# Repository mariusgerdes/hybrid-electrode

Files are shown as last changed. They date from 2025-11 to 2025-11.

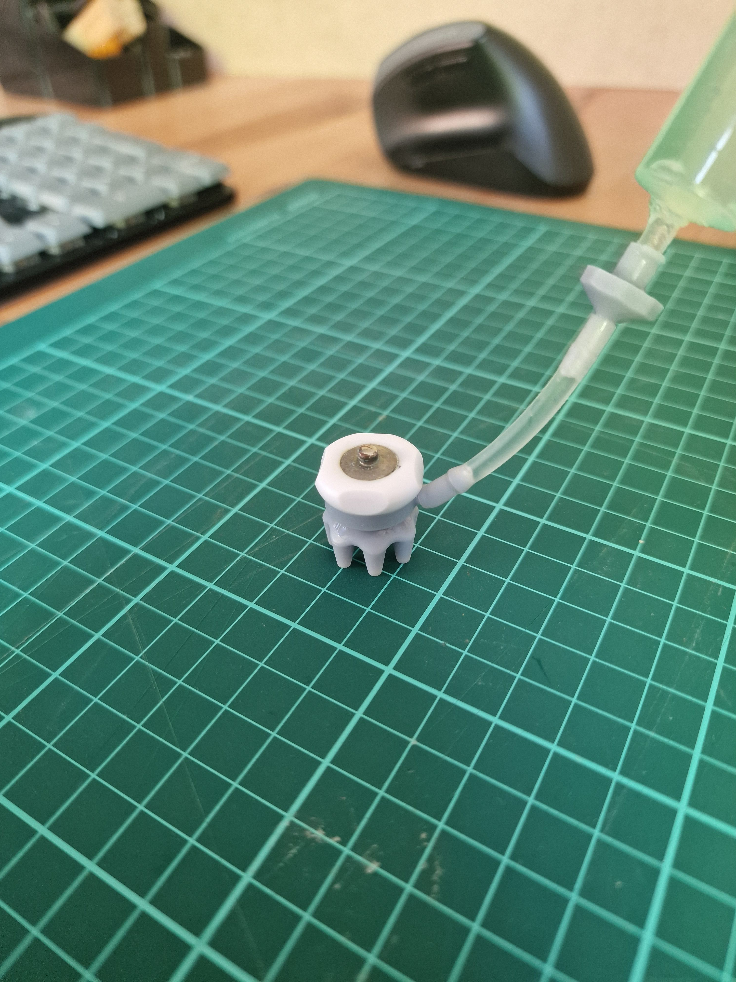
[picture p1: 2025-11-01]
video_and_photo/fillingSyringe.jpg

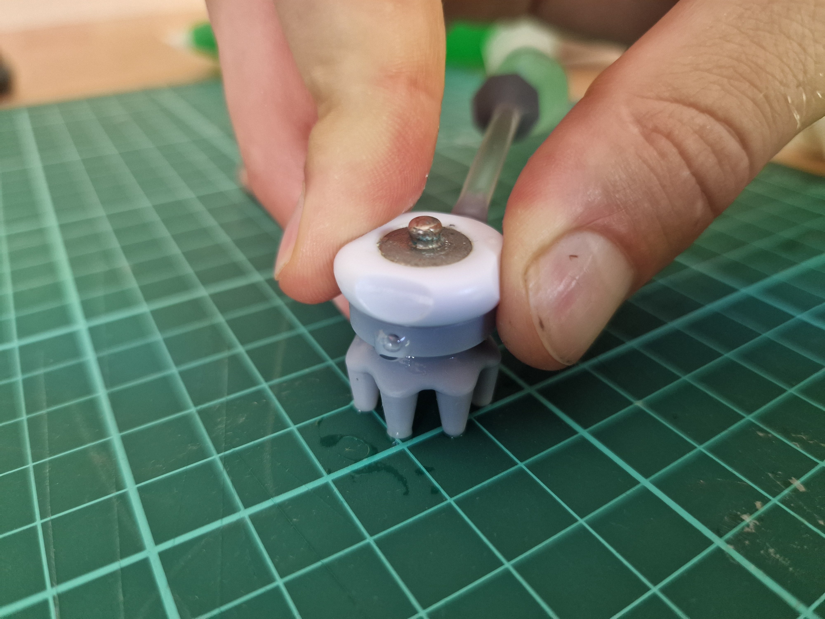
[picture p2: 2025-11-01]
video_and_photo/filledElectrode.jpg

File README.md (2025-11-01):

# RPH-Trode: A Rapid Prototyping Approach to Patient Friendly Hybrid EEG Electrodes



## Authors

**Marius Gerdes¹**, **Simon Stock²**, **Heiko Maier³**, **Lukas Feckl¹**, **Florian Mazura¹**, **Wilhelm Stork¹**

¹ ITIV, Karlsruhe Institute of Technology, Karlsruhe, Germany  
² Faculty of Engineering, TH Rosenheim, Rosenheim, Germany  
³ Computer Aided Medical Procedures, Technical University of Munich, Munich, Germany

## Abstract

The demand for high-quality electroencephalography (EEG) is growing, yet conventional electrodes present a significant bottleneck. Wet electrodes offer excellent signal quality but are hindered by long setup times, gel residue, and signal degradation from drying, making them unsuitable for long-term or mobile use. Conversely, dry electrodes are convenient but often fail to provide the requisite signal-to-noise levels, especially during subject motion. 

This paper introduces a novel hybrid EEG electrode designed to bridge this gap. By employing a closed-loop channel system for precise electrolyte delivery, the electrode combines the signal quality of wet electrodes with the convenience of dry electrodes. We utilized stereolithography (SLA) 3D-printing for easy rapid prototyping of the electrode geometry. 

Experimental validation demonstrates that the hybrid electrode achieves performance comparable to the wet electrode gold standard, maintains stable contact impedance over extended periods, and provides robust signal acquisition during subject motion, including walking. This approach enables high-quality, long-term, and truly mobile EEG recordings, opening new possibilities for both clinical and consumer neurotechnology.

## Keywords

EEG, hybrid electrode, rapid prototyping, SLA, mobile EEG, BCI, SSVEP

## Repository Contents

###  Data & Results
Summary tables of experimental results including:
- Impedance measurements over one-hour recording sessions
- CCA (Canonical Correlation Analysis) performance metrics for SSVEP detection
- Motion artifact analysis across different activity levels (standing, walking 2 mph, walking 4 mph)

See [`data/RESULTS.md`](data/RESULTS.md) for detailed tables.

### 📈 Plots
High-resolution figures from the paper in multiple formats (PDF, PNG):
- Electrode design schematics and comparisons
- Impedance performance over time
- Power spectral density (PSD) analysis
- CCA correlation analysis for SSVEP detection
- Individual channel impedance tracking

See [`plots/README.md`](plots/README.md) for figure descriptions.

### 🎥 Video & Photos
Demonstration materials including:
- **Filling procedure**: Step-by-step video showing gel injection technique
- **Cleaning procedure**: Electrode maintenance and cleaning protocol
- **Photos**: Assembly views, filled electrodes, and preparation tools

See [`video_and_photo/README.md`](video_and_photo/README.md) for details.

### 🖨️ 3D Models
CAD files for reproducing the RPH-Trode electrode:
- STL files ready for 3D printing (resin or FDM)
- STEP files for CAD modification
- Printing instructions and post-processing guidelines

**Original print settings**: Prusa resin printer, high detail preset

See [`3d-models/README.md`](3d-models/README.md) for printing instructions.

## Key Findings

### Impedance Performance
Our one-hour recording sessions revealed:
- **RPH-Trode**: Mean impedance of 85.88 ± 17.33 kΩ with stable performance
- **Dry Electrodes**: Mean impedance of 188.39 ± 14.76 kΩ with gradual increase
- **Wet Electrodes**: Mean impedance of 25.96 ± 2.27 kΩ (lowest) but subject to drying effects

### SSVEP Detection Quality
All electrode types successfully detected SSVEP signals at 7.5 Hz:
- RPH-Trode showed robust performance across all motion conditions
- Clear signal differentiation with CCA ratios > 1.5 for target frequencies
- Maintained performance during walking tasks (2 and 4 mph)

### Signal Quality (PSD Analysis)
Power spectral density analysis demonstrated:
- Comparable alpha band (8-12 Hz) signal quality across electrode types
- Lower noise floor for RPH-Trode compared to dry electrodes
- Consistent performance across multiple recording channels

### Motion Artifacts
Performance across three experimental conditions:
- **Standing** (baseline): All electrodes performed well
- **Walking (2 mph)**: RPH-Trode maintained stable signals
- **Walking (4 mph)**: RPH-Trode showed best motion artifact resistance

## Advantages of RPH-Trode

✅ **High Signal Quality**: Comparable to wet electrode gold standard  
✅ **Long-Term Stable**: Maintains impedance over extended recordings  
✅ **Motion Robust**: Performs well during subject movement  
✅ **User Friendly**: Minimal gel application, easy cleanup  
✅ **Fast Setup**: Quick preparation compared to traditional wet electrodes  
✅ **Rapid Prototyping**: SLA 3D printing enables design iteration  
✅ **Reusable**: Designed for multiple uses with proper cleaning

## Usage

### Viewing the Data
All data tables are provided in markdown format in the [`data/`](data/) directory for easy viewing on GitHub.

### Viewing Figures
High-resolution plots are available in the [`plots/`](plots/) directory in PDF and PNG formats. PDFs provide the best quality for presentations and publications.

### 3D Printing the Electrode
STL files in the [`3d-models/`](3d-models/) directory can be directly used with resin or FDM 3D printers:

- Resin printer (e.g., Prusa SL1)
- High detail preset
- Post-process: IPA wash + UV cure

See the [3D models README](3d-models/README.md) for detailed instructions.

### Electrode Preparation
Watch the demonstration videos in [`video_and_photo/`](video_and_photo/) for:
1. Proper gel filling technique
2. Cleaning and maintenance procedures
3. Assembly verification

## Citation

If you use this work in your research, please cite our paper:

```bibtex
@inproceedings{Gerdes2025_RPHTrode,
  author    = {Gerdes, Marius and Stock, Simon and Maier, Heiko and 
               Feckl, Lukas and Mazura, Florian and Stork, Wilhelm},
  title     = {RPH-Trode: A Rapid Prototyping Approach to Patient Friendly 
               Hybrid EEG Electrodes},
  booktitle = {Integrated Systems in Medical Technologies (ISMT) 2025},
  year      = {2025},
  note      = {Submitted for publication}
}
```

**Note**: Full publication details will be updated once the paper is accepted and published.

## Publication Status

This work has been submitted for publication. The preprint/final version will be linked here once available.

## Contact

For questions, additional data, or collaboration inquiries:

- marius.gerdes@kit.edu

## Related Links

- **KIT ITIV Research Group**: [https://www.itiv.kit.edu/](https://www.itiv.kit.edu/)
- **3D Models and Videos**: Available in this repository

## License

This work is licensed under a [Creative Commons Attribution 4.0 International License](https://creativecommons.org/licenses/by/4.0/).

The 3D models are released under the same license and can be freely modified and distributed with attribution.

## Acknowledgments

We thank all participants who volunteered for the experimental validation studies. This research was conducted in compliance with institutional ethics guidelines.

## Additional Resources

For raw data, detailed analysis scripts, or other materials not included in this repository, please contact the authors directly.

### Requesting Additional Materials

If you need:
- **Raw EEG data files**: Contact the corresponding author
- **Analysis code**: Python scripts available upon reasonable request
- **Custom electrode designs**: We can provide design consultation
- **Collaboration opportunities**: Open to academic and industrial partnerships

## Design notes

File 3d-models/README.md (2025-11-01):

# 3D Models

This directory contains CAD files for the RPH-Trode (Rapid Prototyped Hybrid) electrode design.

## Available Files

- `electrode.stl` - Main electrode body
- `electrode.stp` - STEP file for CAD editing
- `electrode.png` - Preview image
- `lueradapter.stl` - Luer adapter for filling
- `lueradapter.stp` - STEP file for CAD editing  
- `lueradapter.png` - Preview image

## Printing Instructions

### Original Print Settings (Prusa Resin Printer)

These models were successfully printed using. Support structures are part of the 3D models, you should be able to print without supports:

- **Printer**: Prusa resin printer
- **Print Preset**: High Detail Level
- **Technology**: SLA/Resin printing
- **Post-Processing**: 
  - Wash in IPA (isopropyl alcohol)
  - UV cure as per resin manufacturer specifications
  - Clean support structures carefully

### Post-Processing

1. Remove support material carefully
2. Sand contact surfaces if needed
3. Clean thoroughly before assembly
4. Test fit all components before final assembly

## Assembly

Refer to the video_and_photo section

## Materials Needed

- Printed electrode components
- Enobioe Geltrode cap
- Electrode Gel
- Silicon hose for connection to luer adapter
- Syringe for filling

## Safety Notes

- Ensure all materials are biocompatible if used for human subjects
- Clean and sterilize components according to your institution's protocols
- Test electrical connectivity before use

## License

These 3D models are released under CC BY 4.0. You are free to:
- Share and redistribute
- Adapt and modify
- Use commercially

With the requirement to provide attribution to the original authors.

## Questions?

For detailed assembly instructions, material specifications, or troubleshooting, please contact the authors.

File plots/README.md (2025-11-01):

# Plots Directory

This directory contains high-resolution figures from the paper.

## Available Plots

### Electrode Design
- `electrodes_combined_withtube_andlabels.png` - Overview of electrode designs (wet, dry, RPH-Trode)
- `filling.png` - Electrode filling procedure illustration
- `Electrode_Comparison.png` - Visual comparison of different electrode types

### Impedance Analysis
- `impedance_per_channel.pdf` - Individual channel impedance tracking for all 8 channels over one hour

### EEG Signal Quality
- `psd_grid_comparison.pdf/.png` - Power spectral density comparison across electrode types

### SSVEP/CCA Analysis
- `ssvep_cca_comparison.pdf` - Overall CCA correlation comparison across electrode types
- `cca_example_P004_S001_hybrid.pdf` - Example CCA correlation for RPH-Trode during motion tasks
- `cca_example_P004_S001_dry.pdf` - Example CCA correlation for dry electrode during motion tasks

## Usage

All plots are licensed under CC BY 4.0. You are free to use them with proper attribution.

To view PDF files on GitHub, download them for best viewing quality.

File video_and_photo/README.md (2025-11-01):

# Video and Photo Documentation

This directory contains demonstration videos and photos of the electrode system and experimental procedures.

## Available Files

### Videos
- `fillingVideo.mp4` - Demonstration of filling the electrode with conductive gel
- `cleaningVideo.mp4` - Electrode cleaning and maintenance procedure

### Photos
- `electrodeTopAndSide.jpg` - Top and side view of the assembled electrode
- `filledElectrode.jpg` - Electrode filled with conductive gel
- `fillingSyringe.jpg` - Syringe setup for electrode filling
- `filling_utensils.jpg` - Tools and materials needed for filling

## Video Descriptions

### Filling Video (`fillingVideo.mp4`)
Demonstrates the proper technique for filling the RPH-Trode electrode chambers with conductive gel using a syringe. Shows:
- Preparation of filling materials
- Injection technique to avoid air bubbles
- Verification of proper fill level

### Cleaning Video (`cleaningVideo.mp4`)
Shows the maintenance and cleaning procedure for the electrodes after use:
- Disassembly steps
- Cleaning solution recommendations
- Proper drying and storage

## Usage Notes

- Videos are in MP4 format and can be played in any standard media player
- For best viewing, download the files rather than streaming in the browser
- Photos are high-resolution JPG format

## Safety and Best Practices

When preparing electrodes:
1. Use sterile or clean syringes
2. Avoid introducing air bubbles during filling
3. Clean electrodes thoroughly between uses
4. Follow institutional biosafety protocols

## License

These videos and photos are released under CC BY 4.0. You are free to use them with proper attribution.

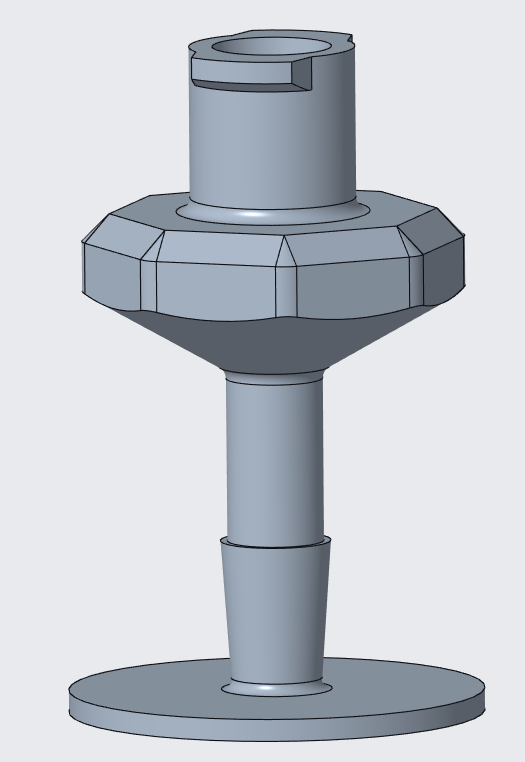
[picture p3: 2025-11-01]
3d-models/lueradapter.png

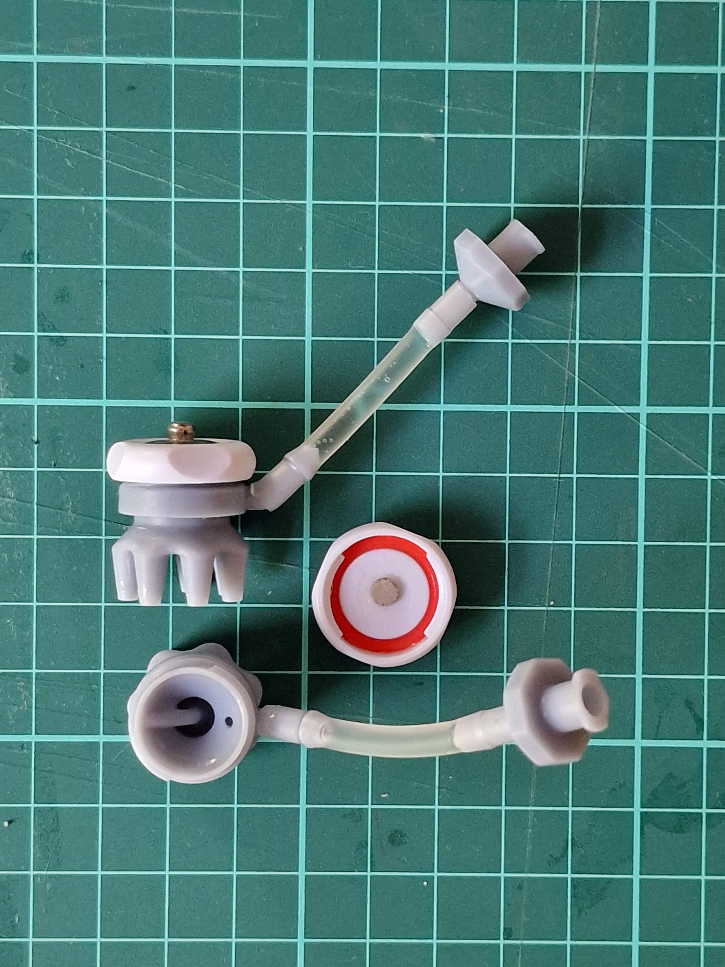
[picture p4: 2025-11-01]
video_and_photo/electrodeTopAndSide.jpg

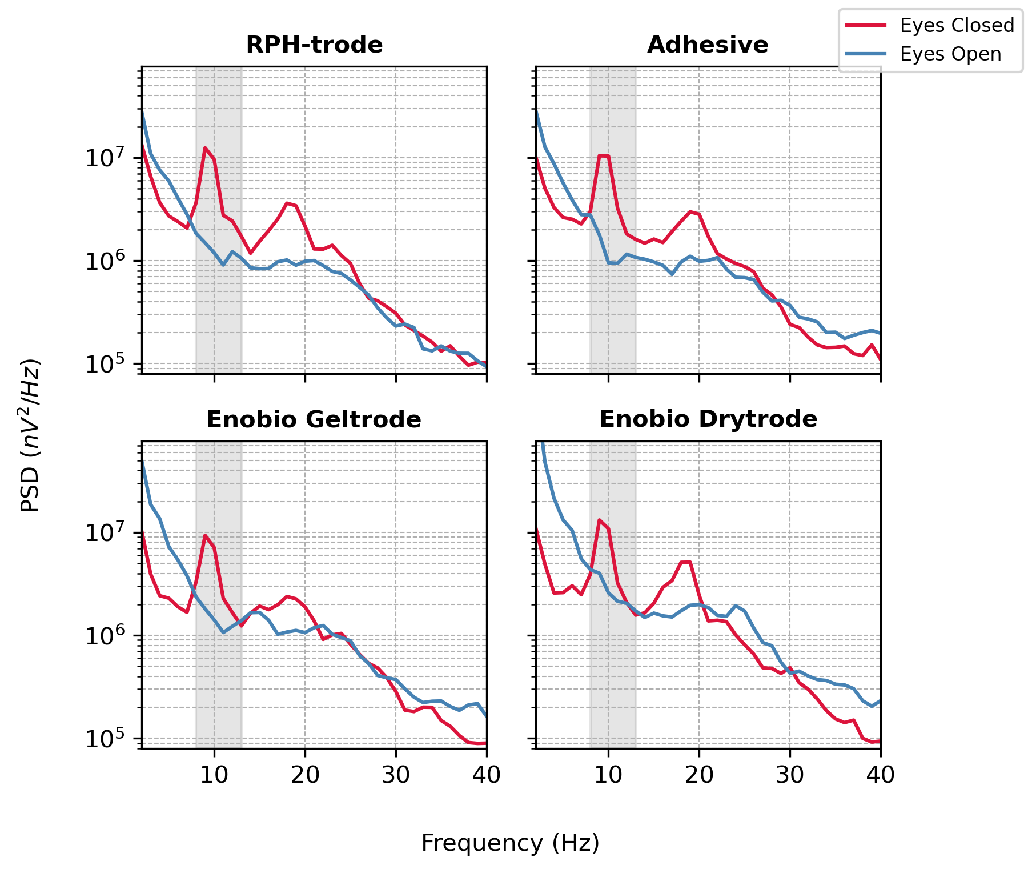
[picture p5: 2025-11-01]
plots/psd_grid_comparison.png

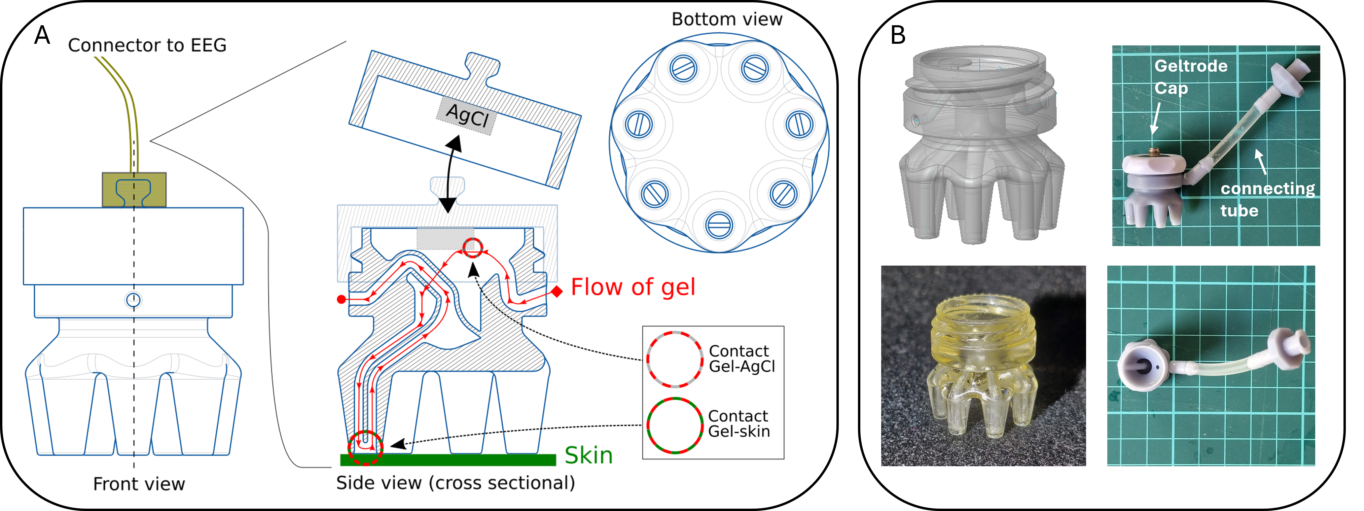
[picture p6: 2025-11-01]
plots/electrodes_combined_withtube_andlabels.png

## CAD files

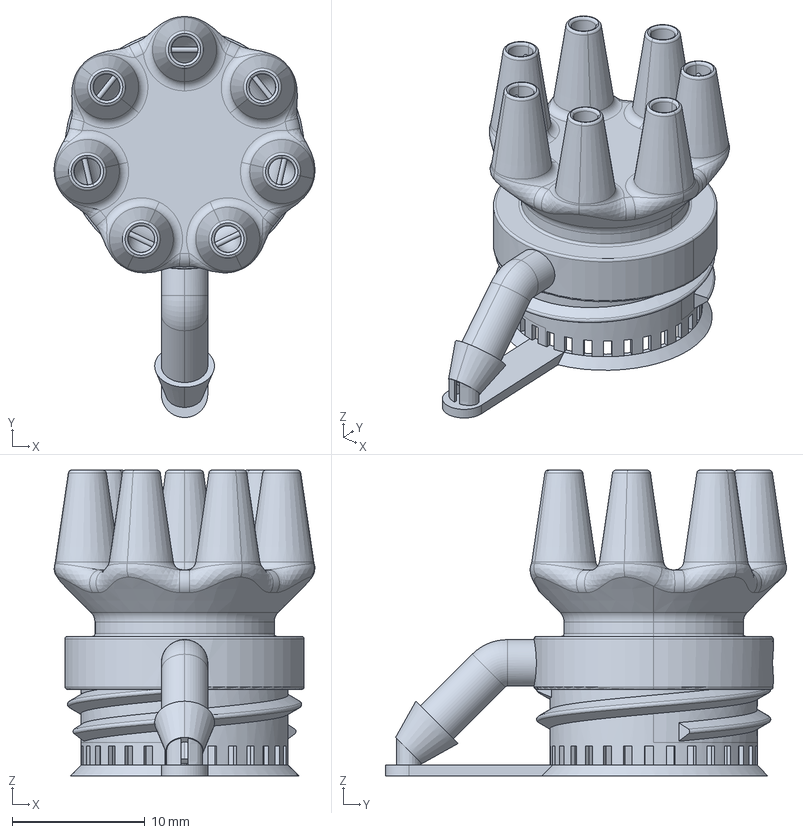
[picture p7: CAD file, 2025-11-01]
3d-models/electrode.stp
19.6 x 30.2 x 23.0 mm

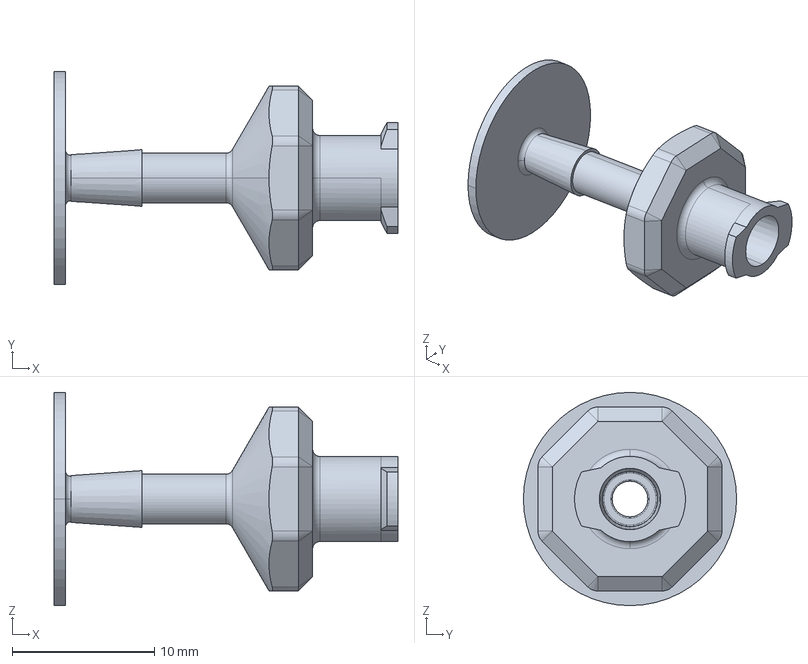
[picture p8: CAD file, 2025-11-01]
3d-models/lueradapter.stp
24.2 x 15.0 x 15.0 mm

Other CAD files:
3d-models/lueradapter.stl

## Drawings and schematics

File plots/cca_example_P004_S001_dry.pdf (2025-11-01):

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

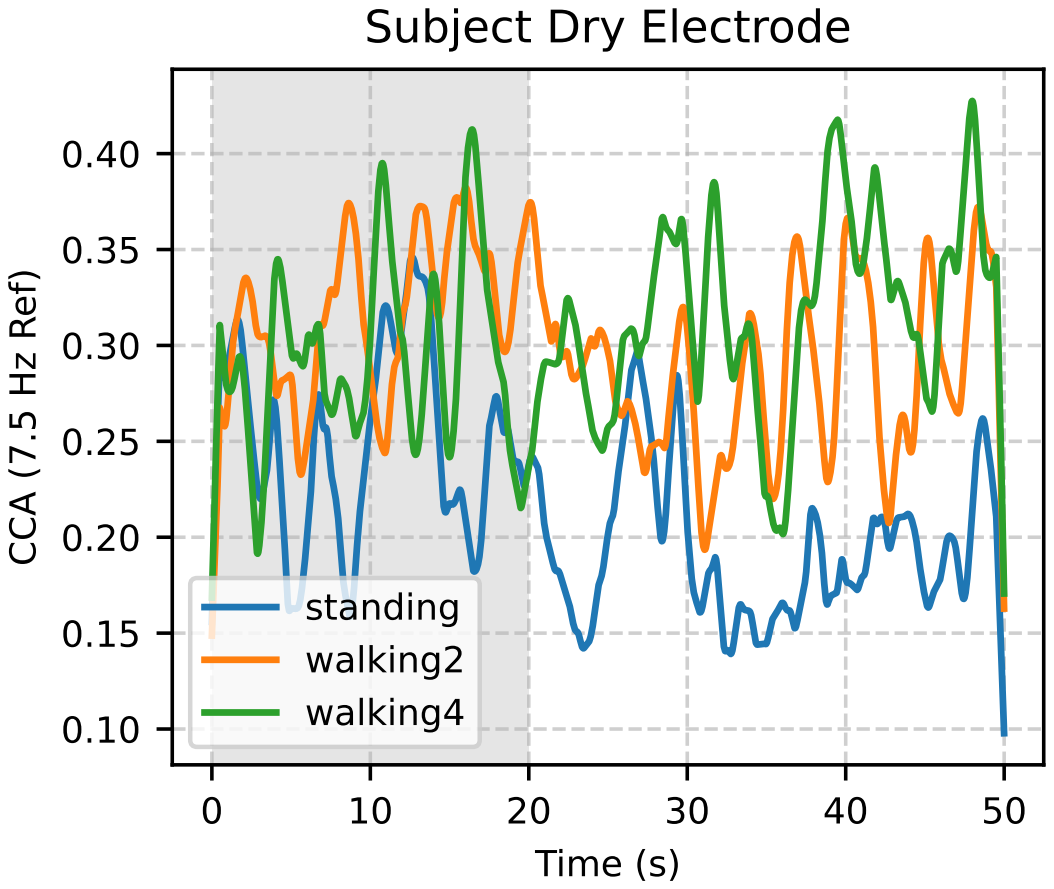
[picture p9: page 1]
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

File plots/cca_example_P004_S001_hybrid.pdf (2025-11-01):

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

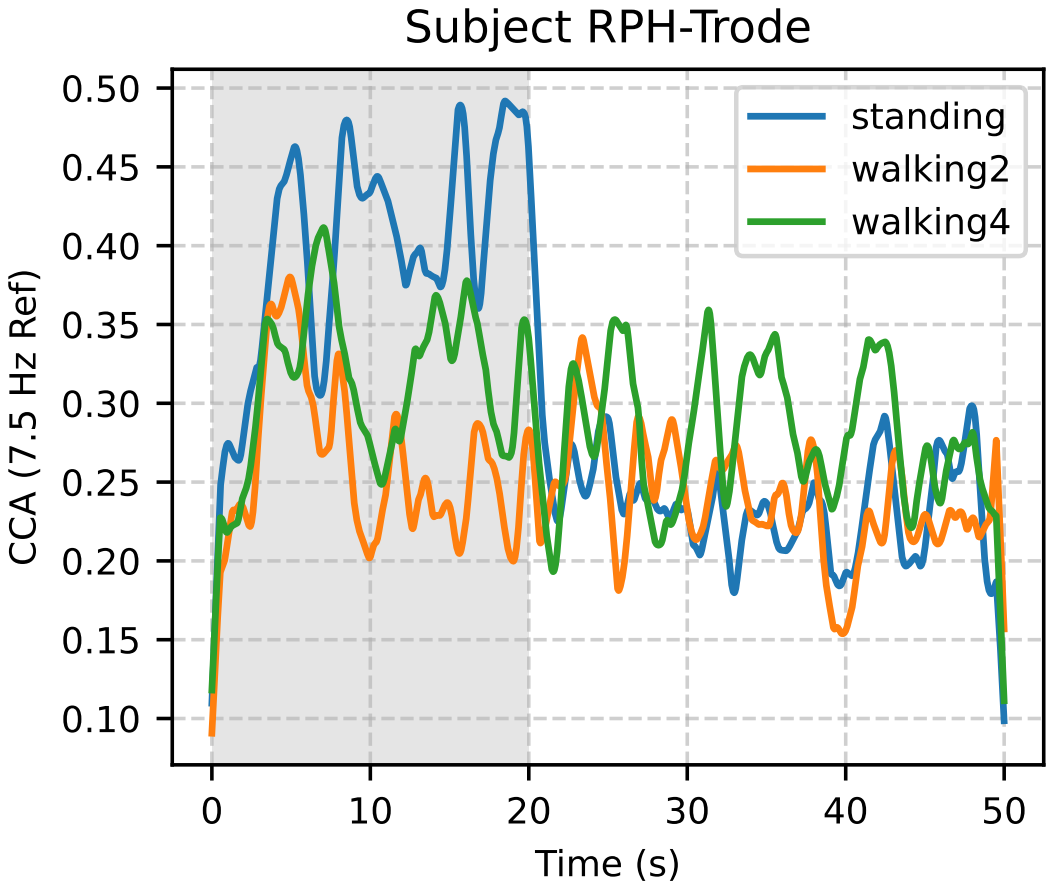
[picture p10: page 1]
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

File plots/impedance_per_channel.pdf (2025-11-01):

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

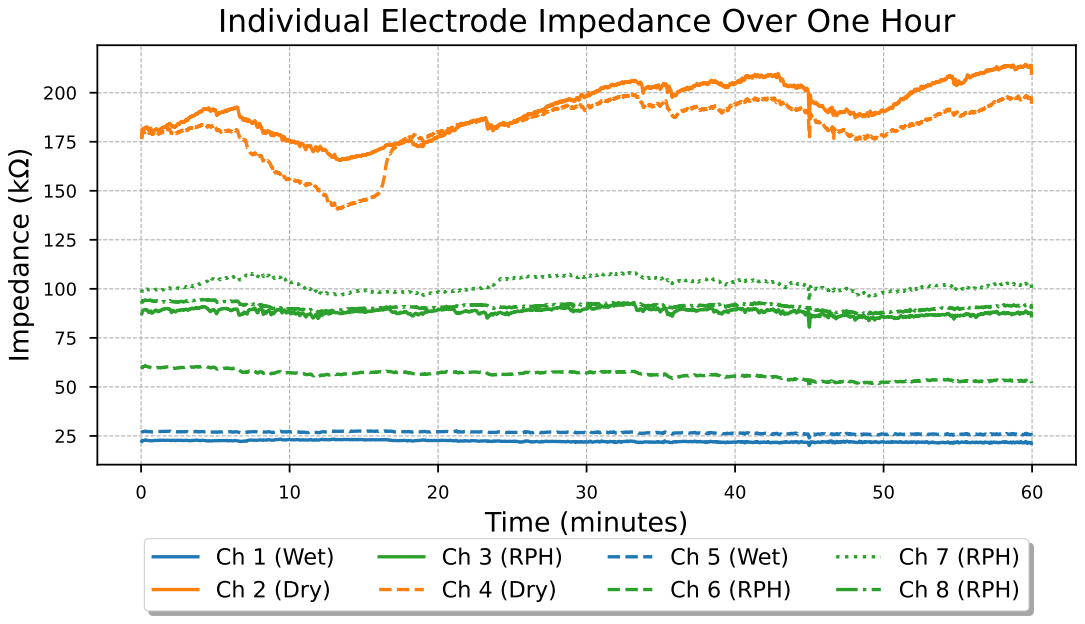
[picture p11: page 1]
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

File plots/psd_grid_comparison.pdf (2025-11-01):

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

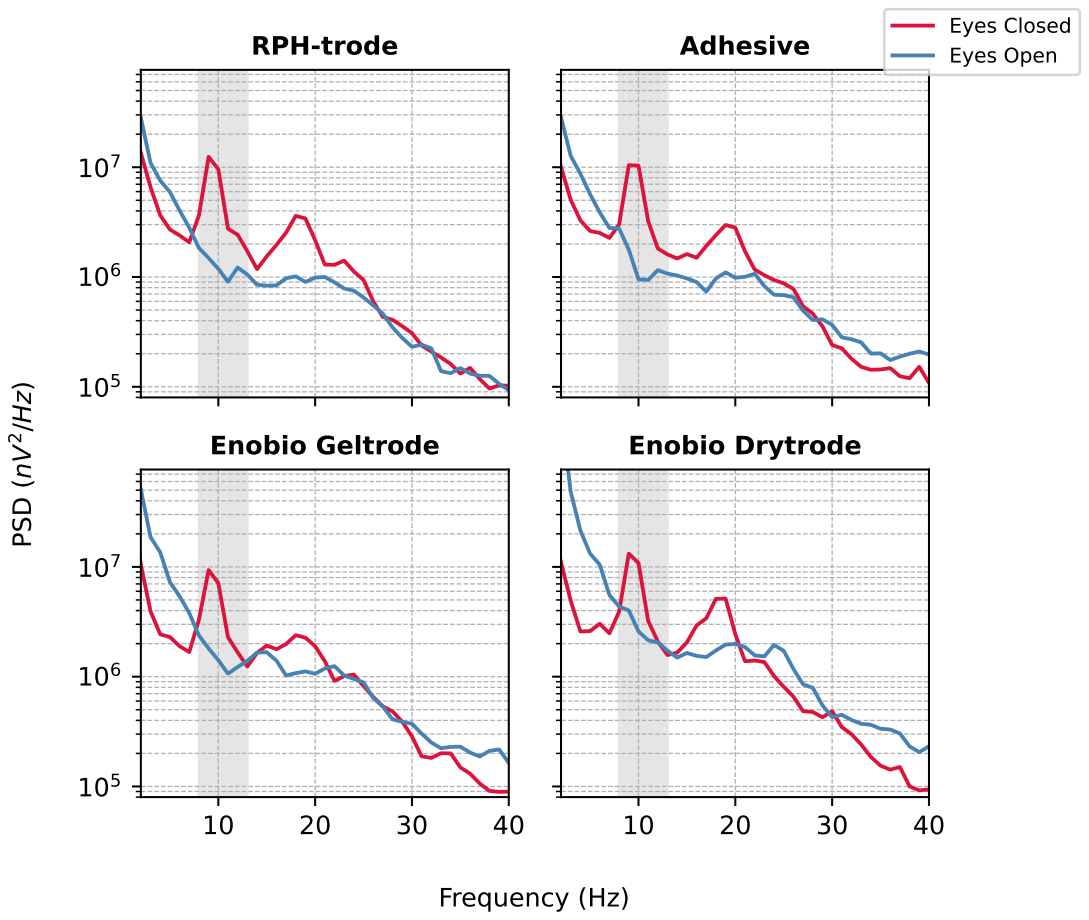
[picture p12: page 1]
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

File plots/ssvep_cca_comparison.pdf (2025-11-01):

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

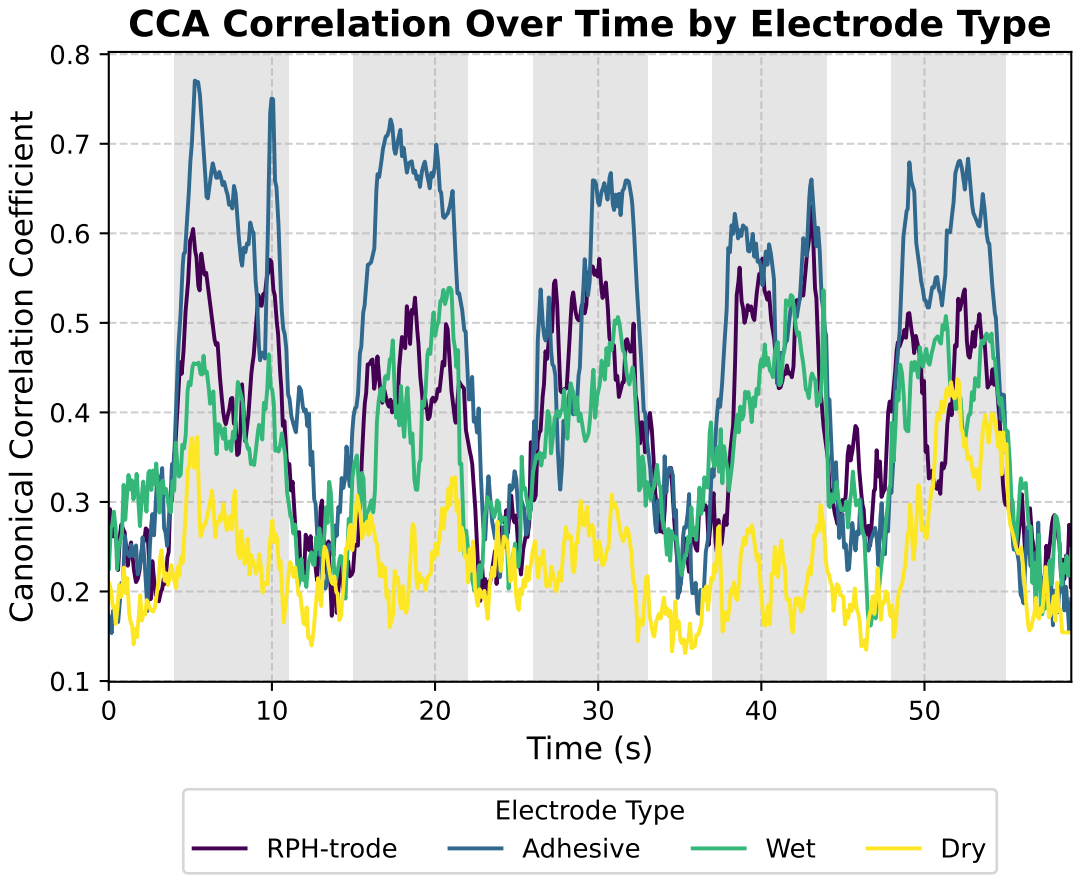
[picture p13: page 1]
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

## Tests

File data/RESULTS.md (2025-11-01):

# Experimental Results - Data Tables

## Impedance Performance Summary

### Individual Channel Impedance Performance (First Hour)

| Channel | Electrode Type | Mean Impedance (kΩ) | Std. Dev (kΩ) |
|---|---|---|---|
| 1 | Wet | 23.77 | 0.59 |
| 2 | Dry | 193.48 | 13.16 |
| 3 | RPH-Trode | 89.75 | 1.76 |
| 4 | Dry | 183.30 | 14.52 |
| 5 | Wet | 28.14 | 0.64 |
| 6 | RPH-Trode | 57.56 | 2.33 |
| 7 | RPH-Trode | 103.69 | 3.34 |
| 8 | RPH-Trode | 92.50 | 1.79 |

### Average Impedance by Electrode Type (First Hour)

| Electrode Type | Mean Impedance (kΩ) | Std. Dev (kΩ) |
|---|---|---|
| Wet | 25.96 | 2.27 |
| Dry | 188.39 | 14.76 |
| RPH-Trode | 85.88 | 17.33 |

## Alpha Band Signal Quality

### SNR for Oz Channel (Eyes Closed vs Eyes Open)

| Electrode Type  | SNR (Alpha EC / Alpha EO) | SNR (Alpha EC / Non-Alpha EC) |
|---|---|---|
| RPH-Trode | 5.68 dB | -2.58 dB |
| Adhesive | 4.80 dB | -2.51 dB |
| Enobio Geltrode | 3.88 dB | -2.85 dB |
| Enobio Drytrode | 1.98 dB | -2.24 dB |

### Average SNR Across All Channels

| Electrode Type  | SNR (Alpha EC / Alpha EO) | SNR (Alpha EC / Non-Alpha EC) |
|---|---|---|
| RPH-Trode | 6.07 dB | -2.49 dB |
| Adhesive | 5.25 dB | -2.24 dB |
| Enobio Geltrode | 3.99 dB | -2.77 dB |
| Enobio Drytrode | 3.18 dB | -2.20 dB |

## SSVEP CCA Performance

### Overall CCA Performance Summary

| Electrode Type | Signal (Avg Stim CCA) | Baseline (Avg Break CCA) | CCA Ratio |
|---|---|---|---|
| RPH-Trode | 0.45 | 0.27 | 1.67 |
| Adhesive | 0.57 | 0.29 | 2.01 |
| Wet | 0.41 | 0.27 | 1.51 |
| Dry | 0.26 | 0.19 | 1.34 |

### Detailed CCA Averages per Stimulation Period

| Electrode Type | Baseline 1 | Stim 1 | Break 1 | Stim 2 | Break 2 | Stim 3 | Break 3 | Stim 4 | Break 4 | Stim 5 |
|---|---|---|---|---|---|---|---|---|---|---|
| RPH-Trode | 0.24 | 0.47 | 0.24 | 0.42 | 0.26 | 0.47 | 0.29 | 0.46 | 0.32 | 0.43 |
| Adhesive | 0.25 | 0.61 | 0.32 | 0.62 | 0.31 | 0.53 | 0.27 | 0.54 | 0.28 | 0.57 |
| Wet | 0.30 | 0.39 | 0.25 | 0.40 | 0.26 | 0.41 | 0.29 | 0.43 | 0.27 | 0.44 |
| Dry | 0.19 | 0.26 | 0.21 | 0.24 | 0.22 | 0.24 | 0.17 | 0.22 | 0.18 | 0.33 |

## Motion Performance Analysis

### CCA Ratio: 7.5Hz Stimulation vs. Breaks (Mean ± Std Dev)

| Electrode | Standing | Walking (2 mph) | Walking (4 mph) |
|---|---|---|---|
| Dry | 1.53 ± 0.45 | 1.14 ± 0.21 | 0.99 ± 0.14 |
| Hybrid | 1.93 ± 0.53 | 1.24 ± 0.31 | 1.21 ± 0.25 |

### CCA Ratio: 7.5Hz Stimulation vs. 10Hz Stimulation (Mean ± Std Dev)

| Electrode | Standing | Walking (2 mph) | Walking (4 mph) |
|---|---|---|---|
| Dry | 1.60 ± 0.41 | 1.14 ± 0.05 | 1.05 ± 0.16 |
| Hybrid | 2.23 ± 0.53 | 1.44 ± 0.49 | 1.27 ± 0.28 |

## Notes

- All values are reported as mean ± standard deviation where applicable
- **CCA** = Canonical Correlation Analysis
- **RPH-Trode** = Rapid Prototyped Hybrid electrode
- **Hybrid** = RPH-Trode in motion experiments
- **EC** = Eyes Closed
- **EO** = Eyes Open
- **SNR** = Signal-to-Noise Ratio (in dB)

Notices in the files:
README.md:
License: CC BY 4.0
